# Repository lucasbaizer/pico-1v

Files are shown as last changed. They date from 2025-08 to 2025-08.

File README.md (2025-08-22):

# PICO 1V IS WIP

The PCB for Pico 1V is still in progress. Don't use it!

# Pico 1V

Pico 1V is an RP2040 board with the following additions/changes from the official Raspberry Pi Pico board:

* Switchable 1.8V/3.3V GPIO.
* A power LED.
* A reset button.
* A USB-C port instead of a Micro-B port.

Pico 1V is sill pin-compatible with the official Raspberry Pi Pico board, so you can use Pico 1V as a drop-in replacement for your existing Pico board.

## Acknowledgements

The schematic for Pico 1V was originally based on [Mitayi-Pico-D1](https://github.com/CIRCUITSTATE/Mitayi-Pico-D1), and the PCB for Pico 1V is from scratch.
Some of the components in the Pico 1V schematic are nearly unchanged from the Mitayi-Pico-D1 schematic.
Huge thanks to CIRCUITSTATE for open-sourcing Mitayi-Pico-D1, it was very helpful for this.

The voltage-switching implementation is based on the method described in [xenia's fantastic blog post](https://blog.awoo.systems/posts/2024-07-27-rp2040-low-voltage-operation).

## License

This project is licensed under the [MIT license](./LICENSE).

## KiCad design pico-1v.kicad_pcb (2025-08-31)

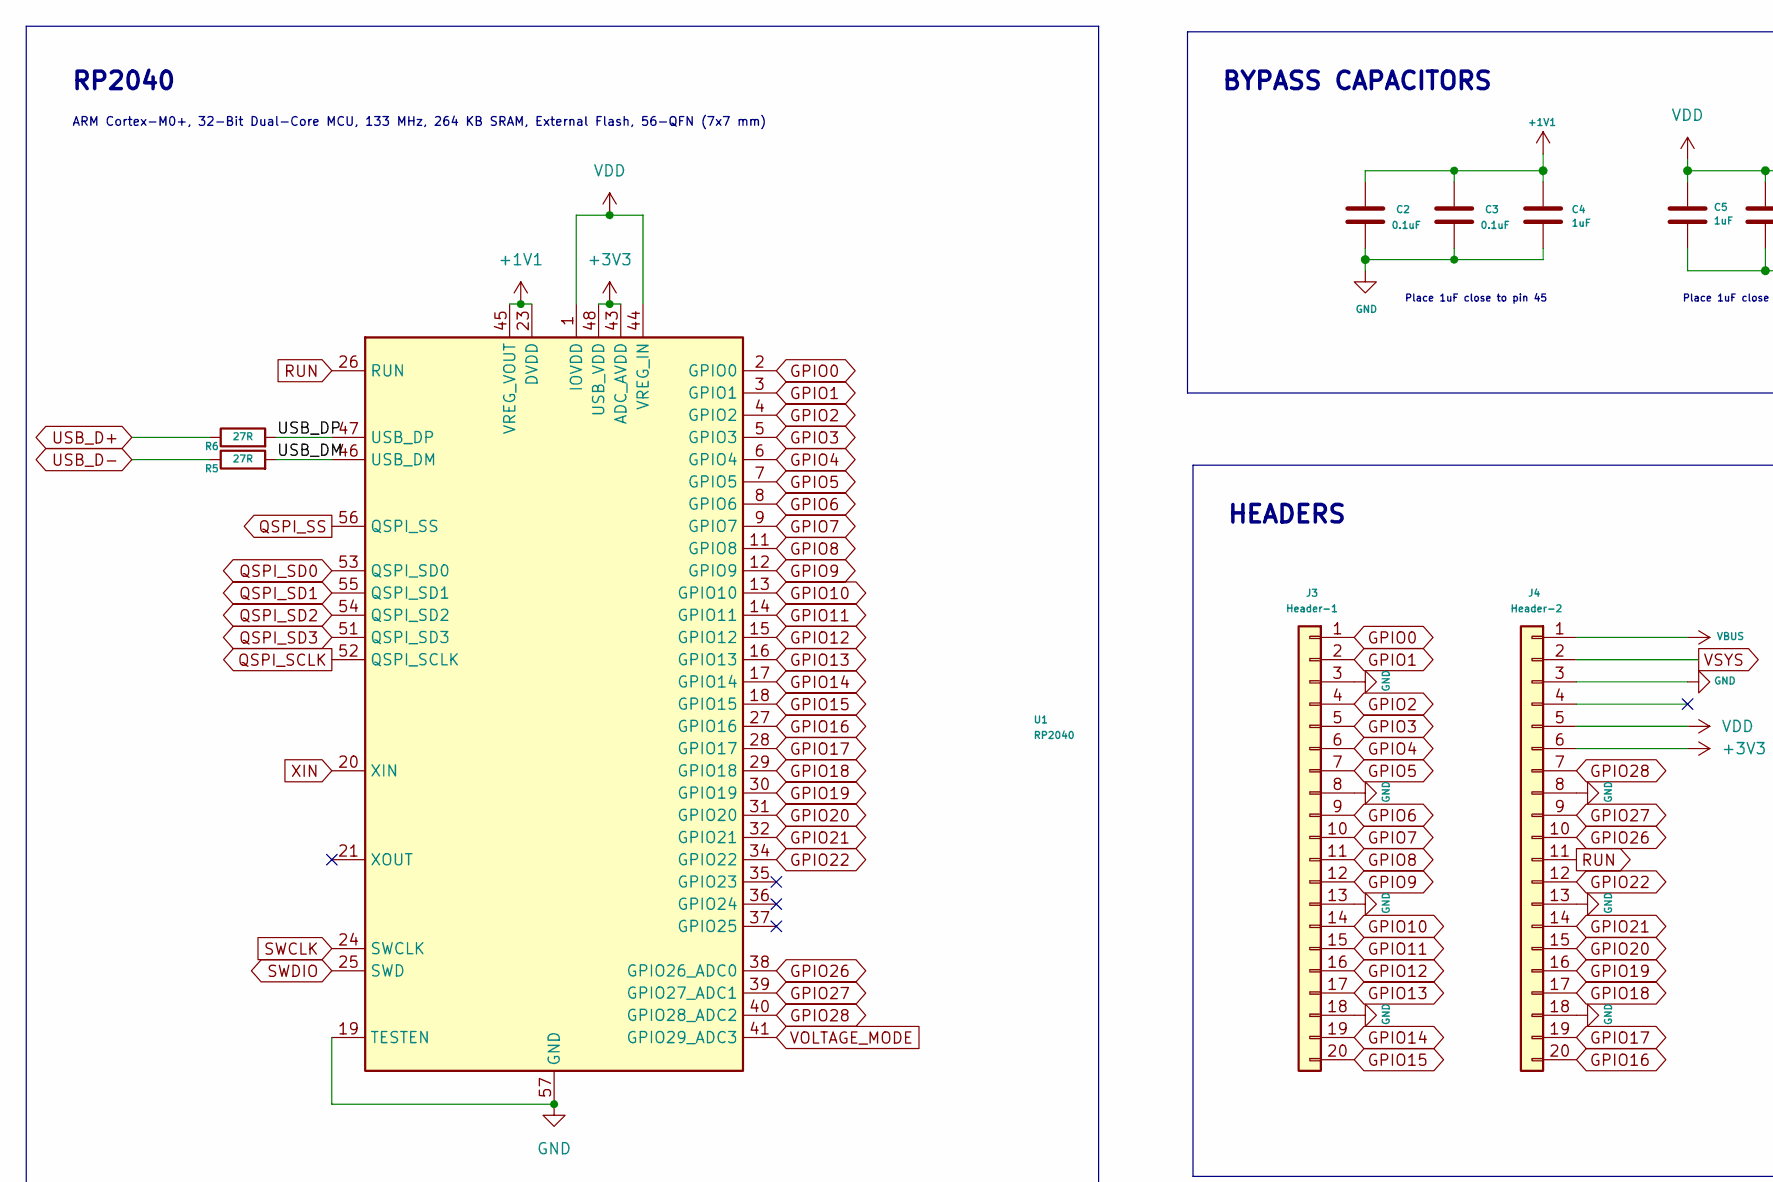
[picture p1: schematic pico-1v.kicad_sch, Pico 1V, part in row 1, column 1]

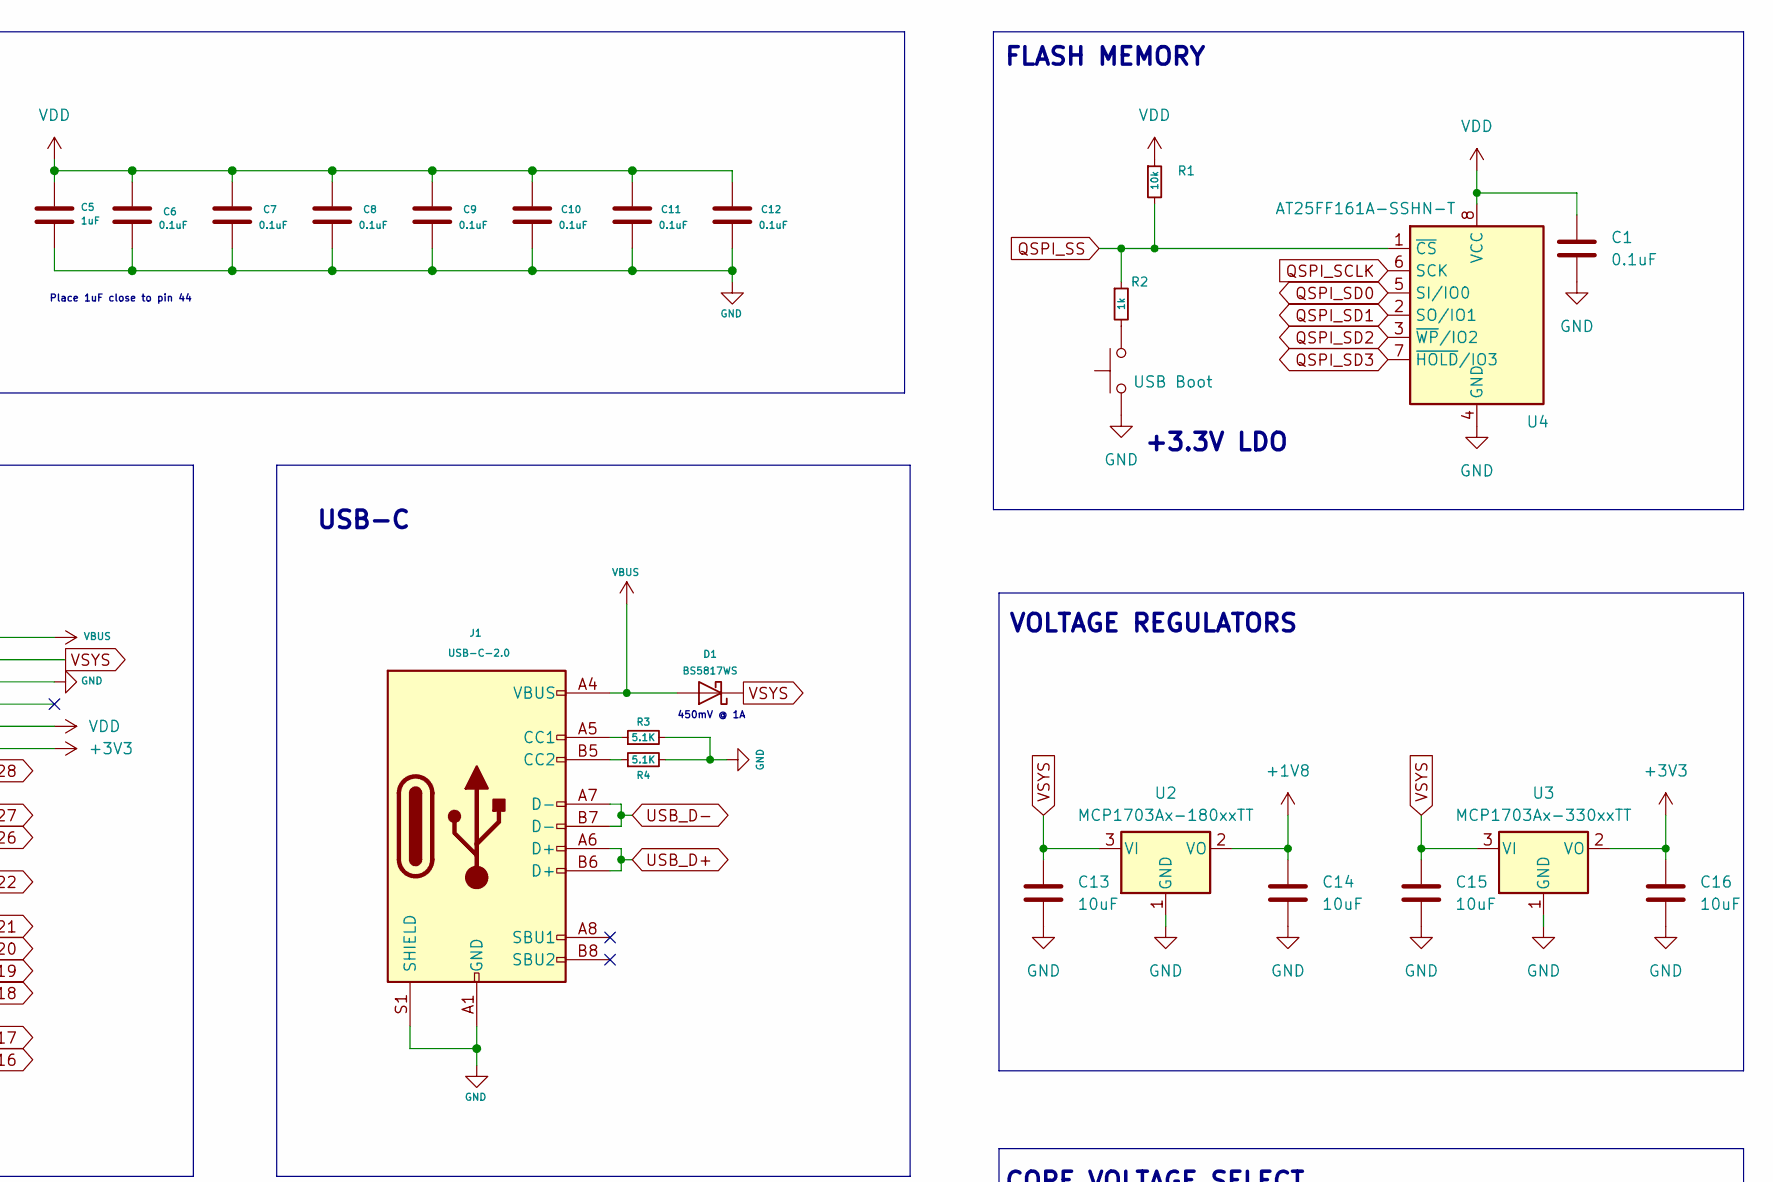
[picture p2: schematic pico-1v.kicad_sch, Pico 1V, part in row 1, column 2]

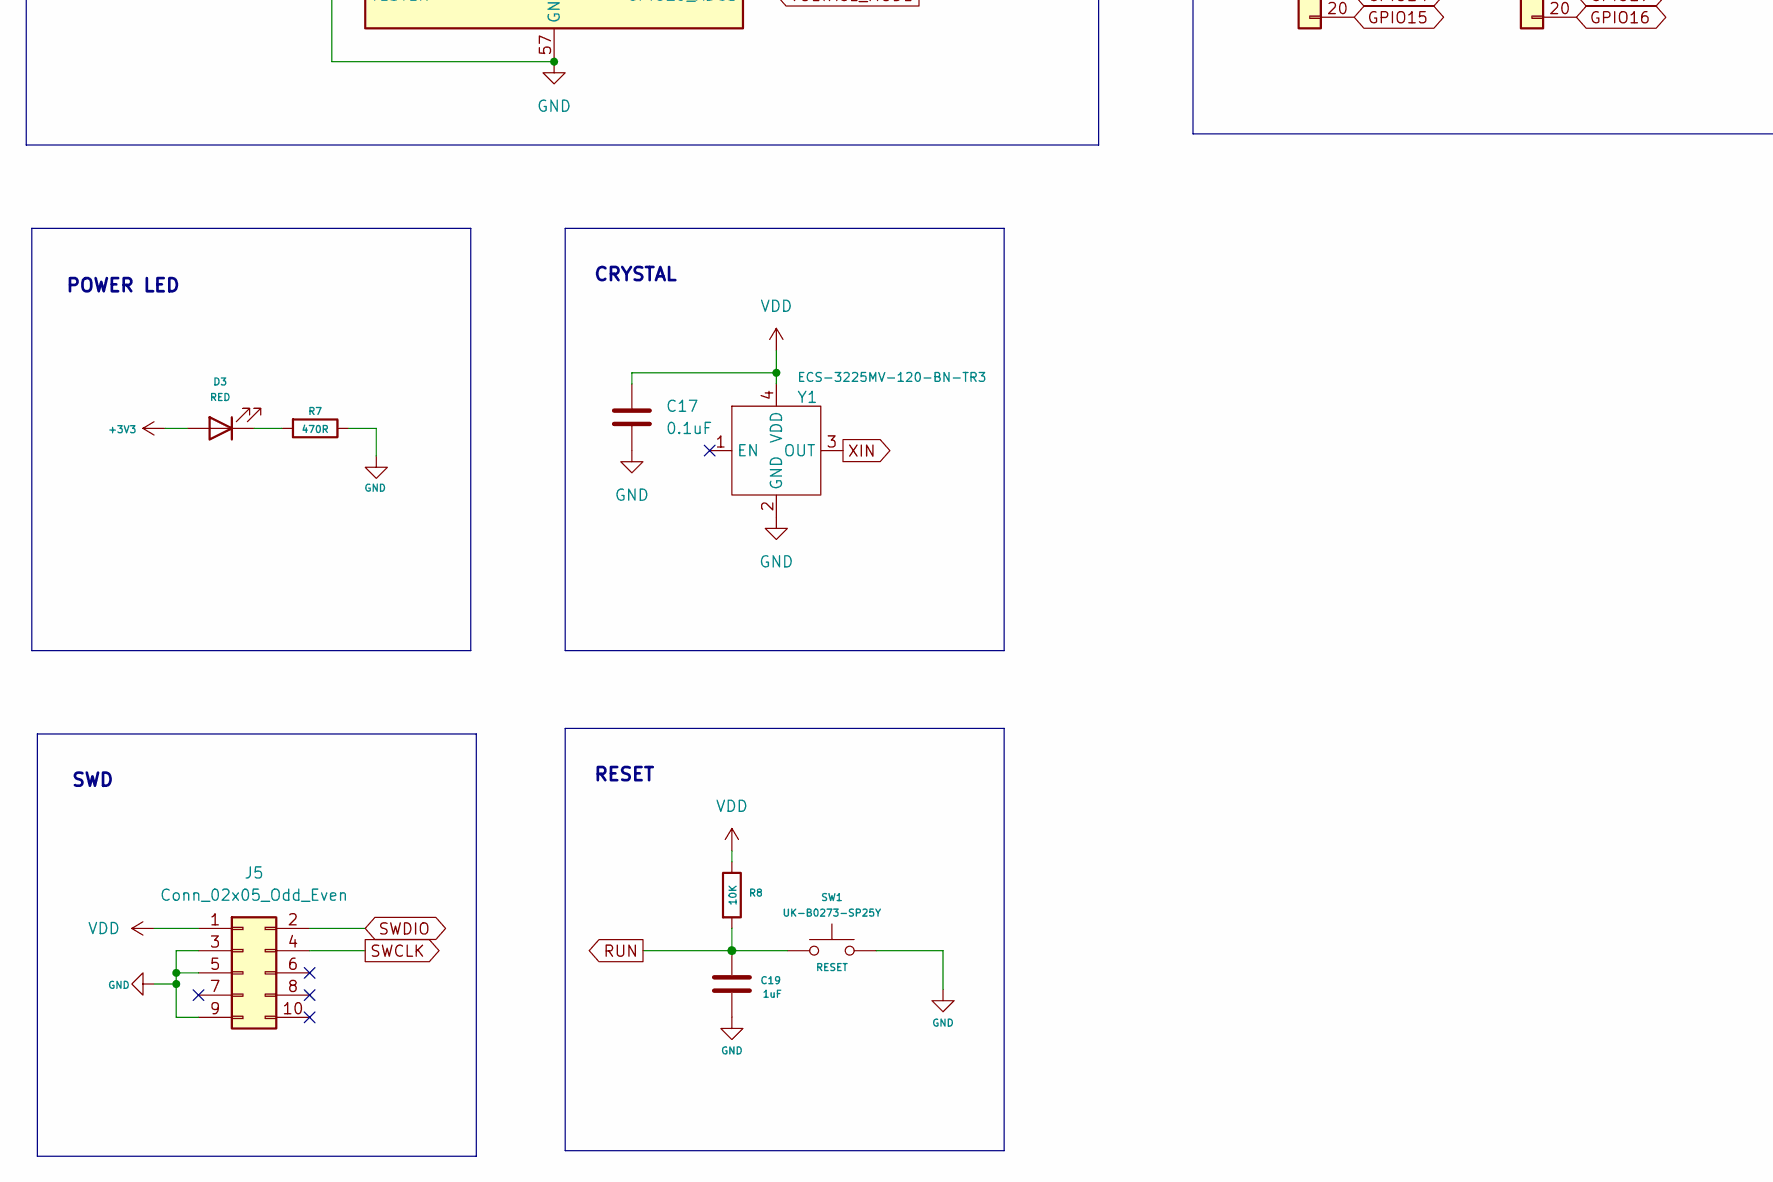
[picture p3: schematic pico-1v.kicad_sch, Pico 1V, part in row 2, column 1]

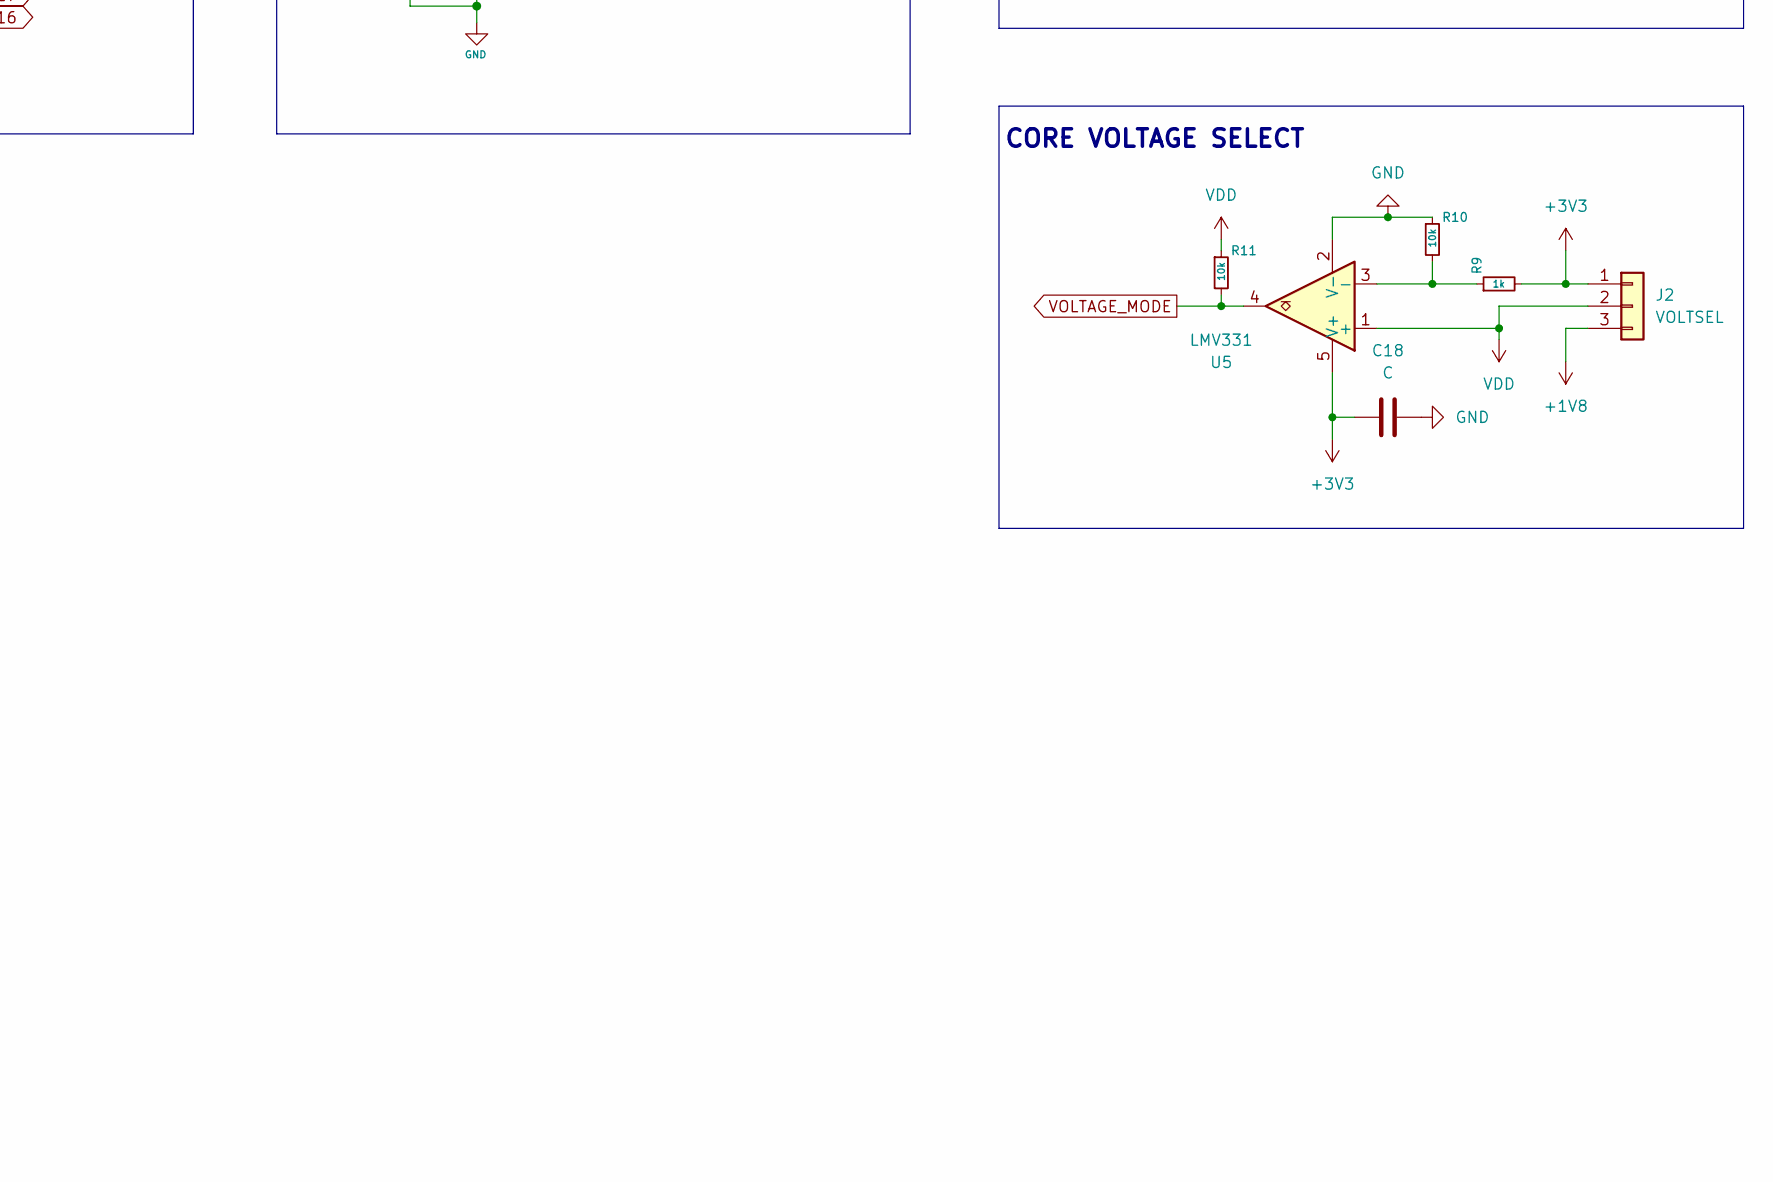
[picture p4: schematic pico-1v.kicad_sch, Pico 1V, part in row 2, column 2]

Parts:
C1, C17: 0.1uF; C_0402_1005Metric
C2, C3, C6, C7, C8, C9, C10, C11, C12: 0.1uF; C_0402_1005Metric; MPN 0402B104K160CT
C4, C5, C19: 1uF; C_0402_1005Metric; MPN 0402X105K160CT
C13, C14, C15, C16: 10uF; C_0402_1005Metric
C18: C; C_0402_1005Metric
D1: BS5817WS; D_SOD-323_HandSoldering; MPN B5817WS
D3: RED; LED_0603_1608Metric; MPN 19-21SURC/S530-A2/TR8
J1: USB-C-2.0; USB_C_RECEPTACLE_31_M_12; MPN HC-TYPE-C-16P-01A
J2: VOLTSEL; PinHeader_1x03_P2.54mm_Vertical
J3: Header-1; PinHeader_1x20_P2.54mm_Vertical; MPN DNP
J4: Header-2; PinHeader_1x20_P2.54mm_Vertical; MPN DNP
J5: Conn_02x05_Odd_Even; PinHeader_2x05_P1.27mm_Vertical_SMD
R1, R10, R11: 10k; R_0402_1005Metric
R2, R9: 1k; R_0402_1005Metric
R3, R4: 5.1K; R_0402_1005Metric; MPN WR04X5101FTL
R5, R6: 27R; R_0402_1005Metric; MPN WR04X27R0FTL
R7: 470R; R_0402_1005Metric; MPN WR04X4700FTL
R8: 10K; R_0402_1005Metric; MPN WR04X1002FTL
SW1: UK-B0273-SP25Y; SW_Push_1P1T_NO_CK_KMR2; MPN UK-B0273-SP25Y
SW2: USB Boot; SW_Push_1P1T_NO_CK_KMR2
U1: RP2040; QFN-56-1EP_7x7mm_P0.4mm_EP3.2x3.2mm; MPN RP2040-B2
U2: MCP1703Ax-180xxTT; SOT-23
U3: MCP1703Ax-330xxTT; SOT-23
U4: AT25FF161A-SSHN-T; SOIC-8_3.9x4.9mm_P1.27mm
U5: LMV331; SOT-353_SC-70-5
Y1: ECS-3225MV-120-BN-TR3

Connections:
+1V1: C2.1, C3.1, C4.1, U1.23 (DVDD), U1.45 (VREG_VOUT), U1.50 (DVDD)
+1V8: C14.1, J2.3, U2.2 (VO)
+3V3: C16.1, C18.1, D3.2 (A), J2.1, J4.6, R9.2, U1.43 (ADC_AVDD), U1.48 (USB_VDD), U3.2 (VO), U5.5 (V+)
/USB_DM: R6.2, U1.46 (USB_DM)
/USB_DP: R5.2, U1.47 (USB_DP)
GND: C1.2, C2.2, C3.2, C4.2, C5.2, C6.2, C7.2, C8.2, C9.2, C10.2, C11.2, C12.2, C13.2, C14.2, C15.2, C16.2, C17.2, C18.2, C19.2, J1.A1 (GND), J1.A12 (GND), J1.B1 (GND), J1.B12 (GND), J1.S1 (SHIELD), J3.3, J3.8, J3.13, J3.18, J4.3, J4.8, J4.13, J4.18, J5.3, J5.5, J5.9, R3.2, R4.2, R7.1, R10.1, SW1.2, SW2.1, U1.19 (TESTEN), U1.57 (GND), U2.1 (GND), U3.1 (GND), U4.4 (GND), U5.2 (V-), Y1.2 (GND)
GPIO0: J3.1, U1.2 (GPIO0)
GPIO1: J3.2, U1.3 (GPIO1)
GPIO2: J3.4, U1.4 (GPIO2)
GPIO3: J3.5, U1.5 (GPIO3)
GPIO4: J3.6, U1.6 (GPIO4)
GPIO5: J3.7, U1.7 (GPIO5)
GPIO6: J3.9, U1.8 (GPIO6)
GPIO7: J3.10, U1.9 (GPIO7)
GPIO8: J3.11, U1.11 (GPIO8)
GPIO9: J3.12, U1.12 (GPIO9)
GPIO10: J3.14, U1.13 (GPIO10)
GPIO11: J3.15, U1.14 (GPIO11)
GPIO12: J3.16, U1.15 (GPIO12)
GPIO13: J3.17, U1.16 (GPIO13)
GPIO14: J3.19, U1.17 (GPIO14)
GPIO15: J3.20, U1.18 (GPIO15)
GPIO16: J4.20, U1.27 (GPIO16)
GPIO17: J4.19, U1.28 (GPIO17)
GPIO18: J4.17, U1.29 (GPIO18)
GPIO19: J4.16, U1.30 (GPIO19)
GPIO20: J4.15, U1.31 (GPIO20)
GPIO21: J4.14, U1.32 (GPIO21)
GPIO22: J4.12, U1.34 (GPIO22)
GPIO26: J4.10, U1.38 (GPIO26_ADC0)
GPIO27: J4.9, U1.39 (GPIO27_ADC1)
GPIO28: J4.7, U1.40 (GPIO28_ADC2)
unnamed: D3.1 (K), R7.2
unnamed: J1.A5 (CC1), R3.1
unnamed: J1.B5 (CC2), R4.1
unnamed: R2.2, SW2.2
unnamed: R9.1, R10.2, U5.3 (-)
QSPI_SCLK: U1.52 (QSPI_SCLK), U4.6 (SCK)
QSPI_SD0: U1.53 (QSPI_SD0), U4.5 (SI/IO0)
QSPI_SD1: U1.55 (QSPI_SD1), U4.2 (SO/IO1)
QSPI_SD2: U1.54 (QSPI_SD2), U4.3 (~WP/IO2)
QSPI_SD3: U1.51 (QSPI_SD3), U4.7 (~HOLD/IO3)
QSPI_SS: R1.2, R2.1, U1.56 (QSPI_SS), U4.1 (~CS)
RUN: C19.1, J4.11, R8.2, SW1.1, U1.26 (RUN)
SWCLK: J5.4, U1.24 (SWCLK)
SWDIO: J5.2, U1.25 (SWD)
USB_D+: J1.A6 (D+), J1.B6 (D+), R5.1
USB_D-: J1.A7 (D-), J1.B7 (D-), R6.1
VBUS: D1.2 (A), J1.A4 (VBUS), J1.A9 (VBUS), J1.B4 (VBUS), J1.B9 (VBUS), J4.1
VDD: C1.1, C5.1, C6.1, C7.1, C8.1, C9.1, C10.1, C11.1, C12.1, C17.1, J2.2, J4.5, J5.1, R1.1, R8.1, R11.1, U1.1 (IOVDD), U1.10 (IOVDD), U1.22 (IOVDD), U1.33 (IOVDD), U1.42 (IOVDD), U1.44 (VREG_IN), U1.49 (IOVDD), U4.8 (VCC), U5.1 (+), Y1.4 (VDD)
VOLTAGE_MODE: R11.2, U1.41 (GPIO29_ADC3), U5.4
VSYS: C13.1, C15.1, D1.1 (K), J4.2, U2.3 (VI), U3.3 (VI)
XIN: U1.20 (XIN), Y1.3 (OUT)

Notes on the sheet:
CORE VOLTAGE SELECT
HEADERS
+3.3V LDO
450mV @ 1A
POWER LED
Place 1uF close to pin 45
RP2040
FLASH MEMORY
SWD
RESET
Place 1uF close to pin 44
CRYSTAL
VOLTAGE REGULATORS
BYPASS CAPACITORS
USB-C
ARM Cortex-M0+, 32-Bit Dual-Core MCU, 133 MHz, 264 KB SRAM, External Flash, 56-QFN (7x7 mm)

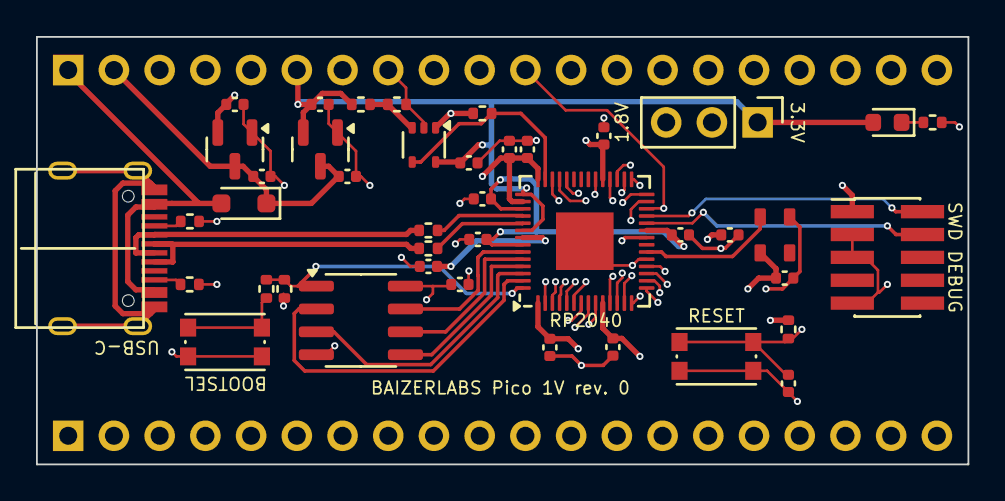
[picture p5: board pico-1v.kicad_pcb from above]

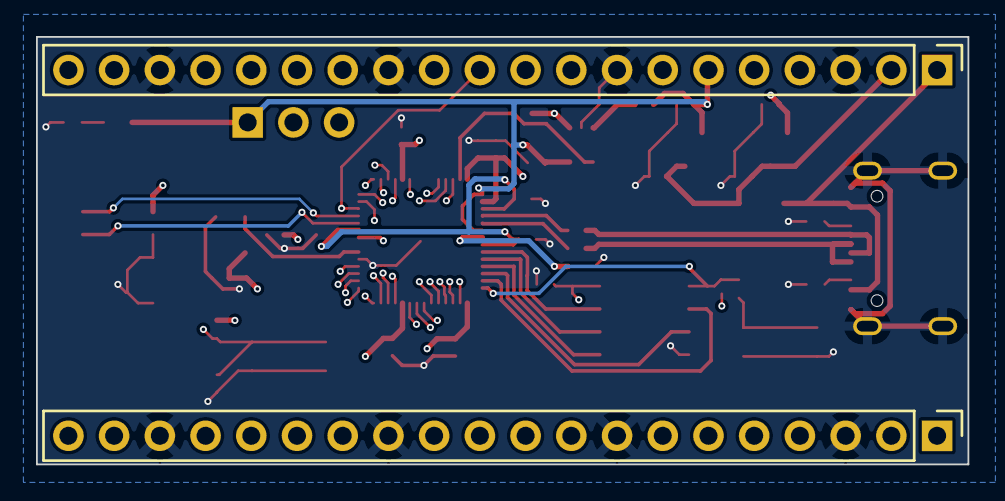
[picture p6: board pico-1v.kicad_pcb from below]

Board: 4 copper layers, 51.8 x 23.8 mm, 44 parts (2 on the bottom side), 53 nets.

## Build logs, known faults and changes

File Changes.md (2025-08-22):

# Changes

#
### **+05:30 10:54:59 AM 27-04-2025, Sunday**

  - Renamed project to `Pico-1V`.
  - Schematic
    - Updated colors.
    - Added `VSYS` net class.
    - Added `Group by MPN-DNP` BoM preset.
  - PCB
    - Imported all changes to the PCB.
    - Updated labels.
    - Added `SWD` signal labels.
    - Added more pin number labels to the top silkscreen.
  - Added KiExport configuration.
  - Added Git scripts.
  - Deleted old manufacturing files.
  - Updated Readme.
  - Generated new manufacturing files.

#
### **+05:30 10:19:35 PM 28-08-2024, Wednesday**

  - Adjusted the PCB thickness to 1 mm from 1.6 mm.
  - Since there are no changes in the designs, new manufacturing files won't be generated.

#
### **+05:30 09:49:49 PM 28-08-2024, Wednesday**

  - Generated manufacturing files.

#
### **+05:30 08:29:15 PM 28-08-2024, Wednesday**

  - Replaced the USB-C connector with a custom one with paste layers on the THT pins. This will help in reliably soldering the USB-C connector.

#
### **+05:30 08:14:38 PM 28-08-2024, Wednesday**

  - Removed the Micro-USB connector from the PCB.

#
### **+05:30 12:01:44 AM 28-08-2024, Wednesday**

  - Updated the silkscreen labels.
  - Added the `D1` variant string to the project info and silkscreen.
  - Added net classes and net highlights in the schematic and PCB.
  - Updated the placements of the OSHW logo.
  - Added `ALT MPN` column to the BoM.
  - Manufacturing files generation pending.

#
### **+05:30 06:51:07 PM 07-04-2024, Sunday**

  - Updated paste layers.
  - Updated BoM.
  - DRC passes.
  - Modified all GND pads on the headers to rectangles.
  - Added board stackup info and board characteristics.
  - Generated manufacturing files

#
### **+05:30 06:02:46 PM 07-04-2024, Sunday**

  - Added USB breakout pads labels.

#
### **+05:30 03:11:20 PM 07-04-2024, Sunday**

  - Added teardrops.
  - Added USB breakout pads on the Back side.

#
### **+05:30 02:23:56 PM 07-04-2024, Sunday**

  - Moved the BTN jumper to the Front side.
  - Updated push-button values.

#
### **+05:30 12:53:11 PM 07-04-2024, Sunday**

  - Replaced DEB_EN jumper with 0R resistor, so that after assembly the board will work out of the box.
  - Replaced `VR1_CE` with 0R resistor. Footprint remains the same.
  - Replaced multiple 0402 hand soldering footprints with regular ones.
  - Replaced the USB-C connector footprint with the KiCad standard footprint.
  - Replaced the `AREF_SEL` jumper with 0R resistor.

#
### **+05:30 11:04:43 PM 02-04-2024, Tuesday**

  - Updated fab layers.

#
### **+05:30 08:04:50 PM 02-04-2024, Tuesday**

  - Updated KiCad project version to V8.
  - Rotated the board -90 degrees. It was hard to work with a vertical board.
  - Cleaned up the schematic. The schematic is now much neater.
  - Updated project details.
  - Updated gitignore.
  - Updated Readme.
  - New revision `R0.6`.

#
### **+05:30 09:32:55 AM 20-02-2023, Monday**

  - New revision 🎯 **r0.5**.
  - Fixed crystal footprint issue.
  - USB-Micro footprint has been masked out to prevent shorting when soldering USB-C connector.
  - Removed AMS1117-3.3 voltage regulator.
  - New dedicated push-button for `BOOTSEL` called `UBUT`, with dual functions.
  - Removed all redundant silkscreen items.
  - New `EXP8` 8-pin expansion connector in 2x4 2.54mm pin header.
  - Changed project type to KiCad 7.
  - Updated solder jumper footprints.
  - Moved OSHW logo to back.

#
### **+05:30 09:54:46 AM 21-09-2022, Wednesday**

  - The r0.3 PCB looks so complicated with its routing. There are 180+ vias for a rather simple board. So I am going to remove all the tracks and start routing afresh. The r0.3 will be saved for reference anyway.

  - Starts 📢 **r0.4**.

#
### **+05:30 05:47:05 PM 05-09-2022, Monday**

  - Added new version info.
  - Added license info.
  - Connected with [CADLAB.io](https://cadlab.io/project/25932). 
  
#
### **+05:30 05:33:45 PM 27-08-2022, Saturday**

  - The crystal I selected was `YIC-12M20P2/XT324-10/10` from YIC. This is a **12MHz** crystal with 20pF required load capacitance. The four pin crystal has signals on the pins `1` and `3`. But unfortunately the r0.2 had the connections to pins `1` and `2`. Not only that, the `GND` pins of the crystals were never connected. I had to apply a jumper-fix on the r0.2 board as a temporary workaround to get the board working.

  - The capacitor value for the crystal has been changed to **20pF** from 25pF. This is because I thought the capacitors were the problem. RP2040 works fine with 20pF. The approximate capacitor value required is 30pF according to the calculations. 

  - Added a second push-button that can be selected between **Reset** (`RUN`) or **GPIO** (`GPIO2`) functions. The Reset function will only be needed rarely (for example, I used it to recover the RP2040 from a *soft-brick* after I changed the clock selection to 300MHz in the Arduino IDE). So in all other cases, the user can use the push-button as a user input button.

  - I also soldered the `R1` (10K) thinking that could have been the issue. Adding it did not change anything and the board works fine with that in place. R1 is only recommended for some versions of the Flash chip.

  - Removed the secondary voltage regulator.

  - Removed `AREF_VDD` jumper. It is now connected to 3.3V.

  - Starts 📢 **r0.3**.

#
### **+05:30 08:46:57 PM 19-08-2022, Friday**

  Added new `Revisions` folder. When a revision is completed, the projected can be saved to this folder using the **Save As** option in KiCad. This is in addition to generating a git revision. The project must be saved with the revision number at the end, for example ***"Mitayi-Pico-RP2040-r0.2"***. KiCad will complain about recursive folders but you can ignore them. Just delete the recursive `Revisions` folder from the the project that was just saved to the new `Revisions` folder.

  I just saved the version **🎯 r0.2**. Revisions, once saved, should not be modified. Make all the modifications on the root project.

#
### **+05:30 07:03:26 PM 26-08-2021, Thursday**

  I made a few mistakes in the v0.1 design. Some of the vias were placed on top of the pads. While this is not a big issue, PCBWay complained about this. They said the solder mask won't be applied on such vias, which is okay. Still, placing vias on pads is not a good idea. So I modified the design and moved all the vias from pads.

  Another issue is, whenever I am trying to run DRC check, KiCad would crash and leave some ghost processes that I can not terminate. I suspect the DRC crashes because the board has filleted tracks. Launching KiCad after crash is not a problem. It works fine after that. But I am not able to run DRC 😟

  Other than that, I added the Diode to VBUS and created the new VSYS signal. The pinouts has been changed. I removed BOOT_SEL from the header. Also, the supply pin side on the header is now compatible with RPi Pico. I am not going to add TVS diodes on the USB lines yet.

  Some of the via drill sizes were less than 0.3mm. I have now changed all of them to 0.5/0.3mm.

  I am going to keep the few filleted tracks and going to generate new Gerbers. Let's see what happens. This will be **🎯 r0.2**

#
### **+05:30 10:41:48 PM 25-08-2021, Wednesday**

  **Mitayi Pico** is an improved version of **Raspberry Pi Pico**. Mitayi Pico is based on the minimal design for **RP2040** published by RPi. Many cost cutting decisions were went into the design of RPi Pico. Lack of USB Type-C and Reset button are some of that. Mitayi Pico address that and many other limitations of RPi Pico. The differences are,

  1. The original Pico PCB design is created using Altium and files are available for download. But a similar design based on any affordable open source software such as KiCad was not available. Only the minimal board design was available.

  2. RPi Pico doesn't break out all the pins. Mitayi Pico does.

  3. RPi Pico uses buck-boost converter, which can be hard to find or costly. I wanted normal LDOs. Mitayi Pico has that + it has dual regulator option.

  4. RPi Pico's components are small (0201), making it harder to hand-solder. Mitayi uses 0402 and larger packages.

  5. RPi Pico only has Micro-USB. Mitayi Pico has both Type-C and Micro-USB options.

  6. Flash memory chip package is small and hard to hand-solder when we want to change the capacity. Mitayi uses SOIC-8 package which is easily solderable.

  7. RPi Pico doesn't have a RESET button. Mitayi does.

  8. RPi Pico and Mitayi Pico have different pinouts.

  9. Debug LED has solder jumper to disconnect it from the GPIO pin.

  10. RPi Pico and Mitayi Pico share the same dimensions of 21 mm x 50 mm, with almost the same positions for mounting holes.

  11. Component references are not present on the silkscreen of RPi Pico. Mitayi Pico has all the reference to help in manual assembly.

  The word "Mitayi" means Confectionary in Malayalam and Hindi. Mitayi will be a series of boards **CIRCUITSTATE Electronics** will develop. I am still not sure whether to name the new board "Pico" because that might create confusion with the original Pico. I have to find a unique name.

  I have finished the **🎯 v0.1** of the Pico. But it needs some changes. I will commit this version to be used as the base. The changes needed are,

  1. I need to add a reverse protection diode MBR120 to the VBUS line. This will create a new signal VSYS. It has to be broken out, replacing V_EN from the header.

  2. Have to add USB data line TVS diodes.

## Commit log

2025-08-22 Initial Pico 1V commit
    [Amphenol-USB-Tyep-C-Receptacle-12401598E4#2A.STEP, C&K-Tactile-Switch-PTS820J20KPSMTRLFS.stp, ESP01-RP2040-Pin-Mapping.xlsx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]
2025-08-22 More improvements to schematic
    [pico-1v.kicad_pcb, pico-1v.kicad_sch]
2025-08-22 Schematic fixes
    [pico-1v.kicad_sch]
2025-08-22 Updated some stuff
    [pico-1v.kicad_sch]
2025-08-25 Rev 1 PCB
    [pico-1v.kicad_pcb, pico-1v.kicad_sch]
2025-08-29 Fixed for production
    [pico-1v.kicad_pcb]
2025-08-29 More stuff
    [pico-1v.kicad_sch]
2025-08-31 Various fixes
    [pico-1v.kicad_pcb, pico-1v.kicad_sch]
